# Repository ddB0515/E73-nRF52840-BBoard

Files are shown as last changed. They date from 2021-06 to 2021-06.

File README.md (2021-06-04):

nRF52840-BBoard

Based on Ebyte E73 module with nRF52840
More details here: https://www.ebyte.com/en/product-view-news.aspx?id=445

Managed to fit all into breakout board (4 layers) with Lipo charger (not yet tested fully) and USB-C with modified Adafruit nRF52 Bootloader
https://github.com/ddB0515/Adafruit_nRF52_Bootloader/tree/nrf52840-bboard

when managed to build and get bootloader you need to flash it (I have JLink so was easy to get it flashed)
Double click on reset button to get into DFU mode

Bootloader is in `bootloader` folder and should work if you don't wanna build it

To flash it with JLink all you need is in `bootloader` folder:
nrf52840_bboard_bootloader-0.5.1-2-g881dac1-dirty_s140_6.1.1.hex

To update it via serial(if already flashed via Jlink)

`
adafruit-nrfutil --verbose dfu serial --package nrf52840_bboard_bootloader-0.5.1-2-g881dac1-dirty_s140_6.1.1.zip --port /dev/ttyACM0 -b 115200 --singlebank --touch 1200
`

# Interactive BOM
[Interactive BOM](http://htmlpreview.github.io/?https://raw.githubusercontent.com/ddB0515/nRF52840-BBoard/main/bom/ibom.html)

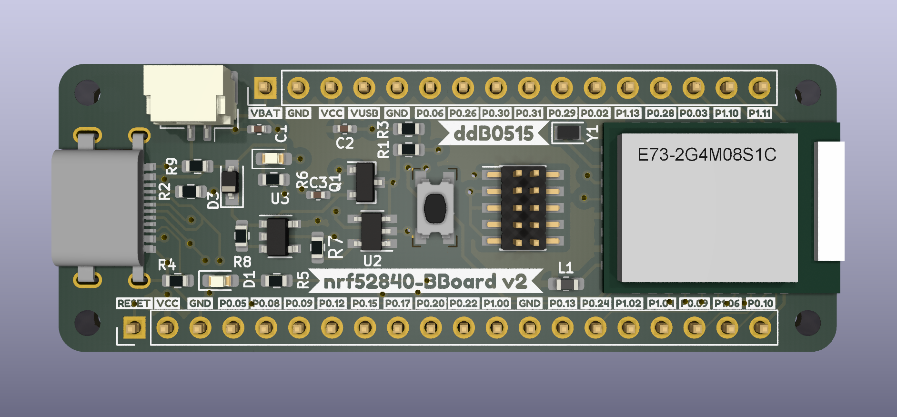
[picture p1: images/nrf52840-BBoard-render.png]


# TODO
- Submit board to Adafruit Bootloader repo
- Add board to Communitiy nRF52 (https://github.com/jpconstantineau/Community_nRF52_Arduino)
- Get more samples/demos to provide with board

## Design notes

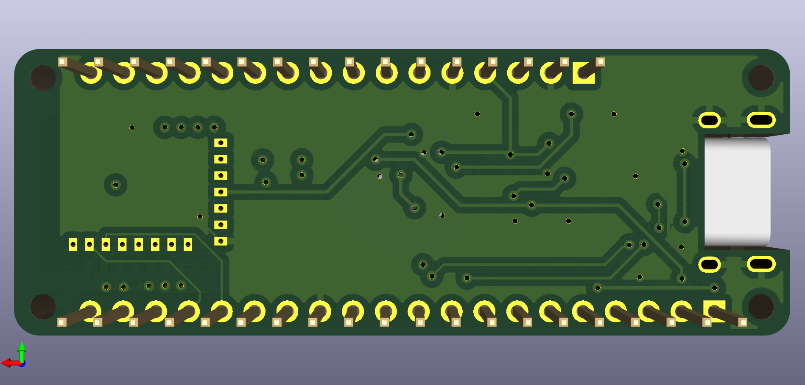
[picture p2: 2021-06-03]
images/nrf52840-BBoard-back.png

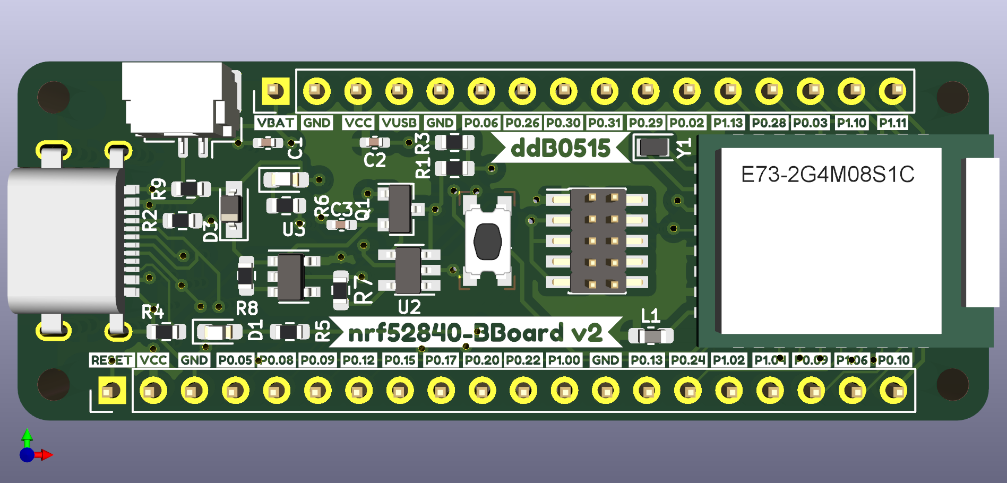
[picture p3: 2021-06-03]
images/nrf52840-BBoard-front.png

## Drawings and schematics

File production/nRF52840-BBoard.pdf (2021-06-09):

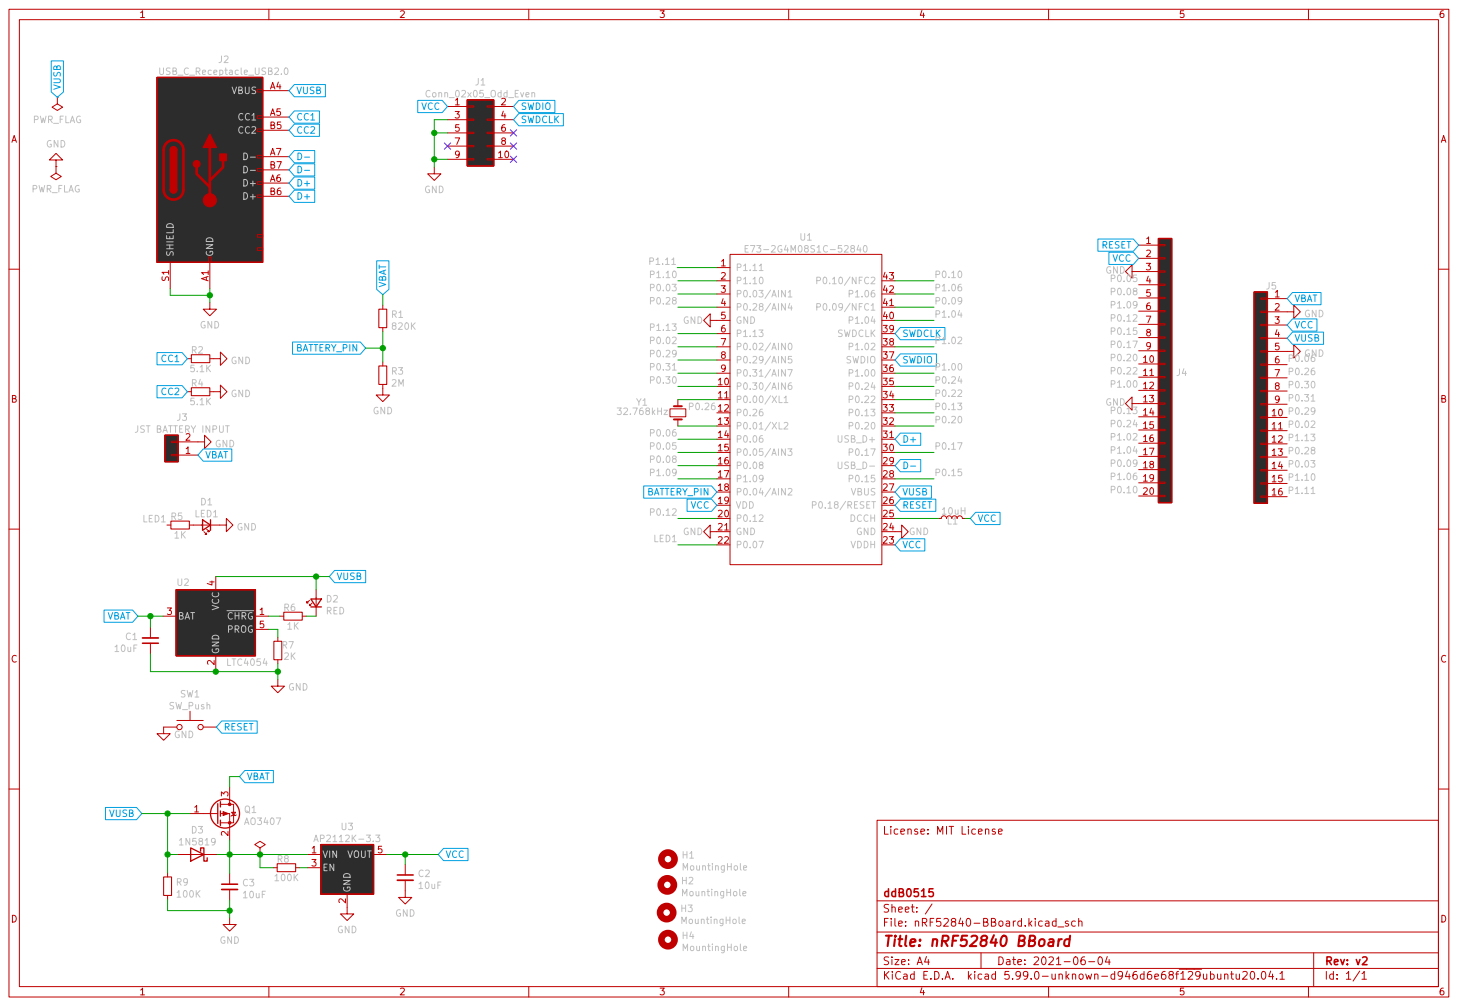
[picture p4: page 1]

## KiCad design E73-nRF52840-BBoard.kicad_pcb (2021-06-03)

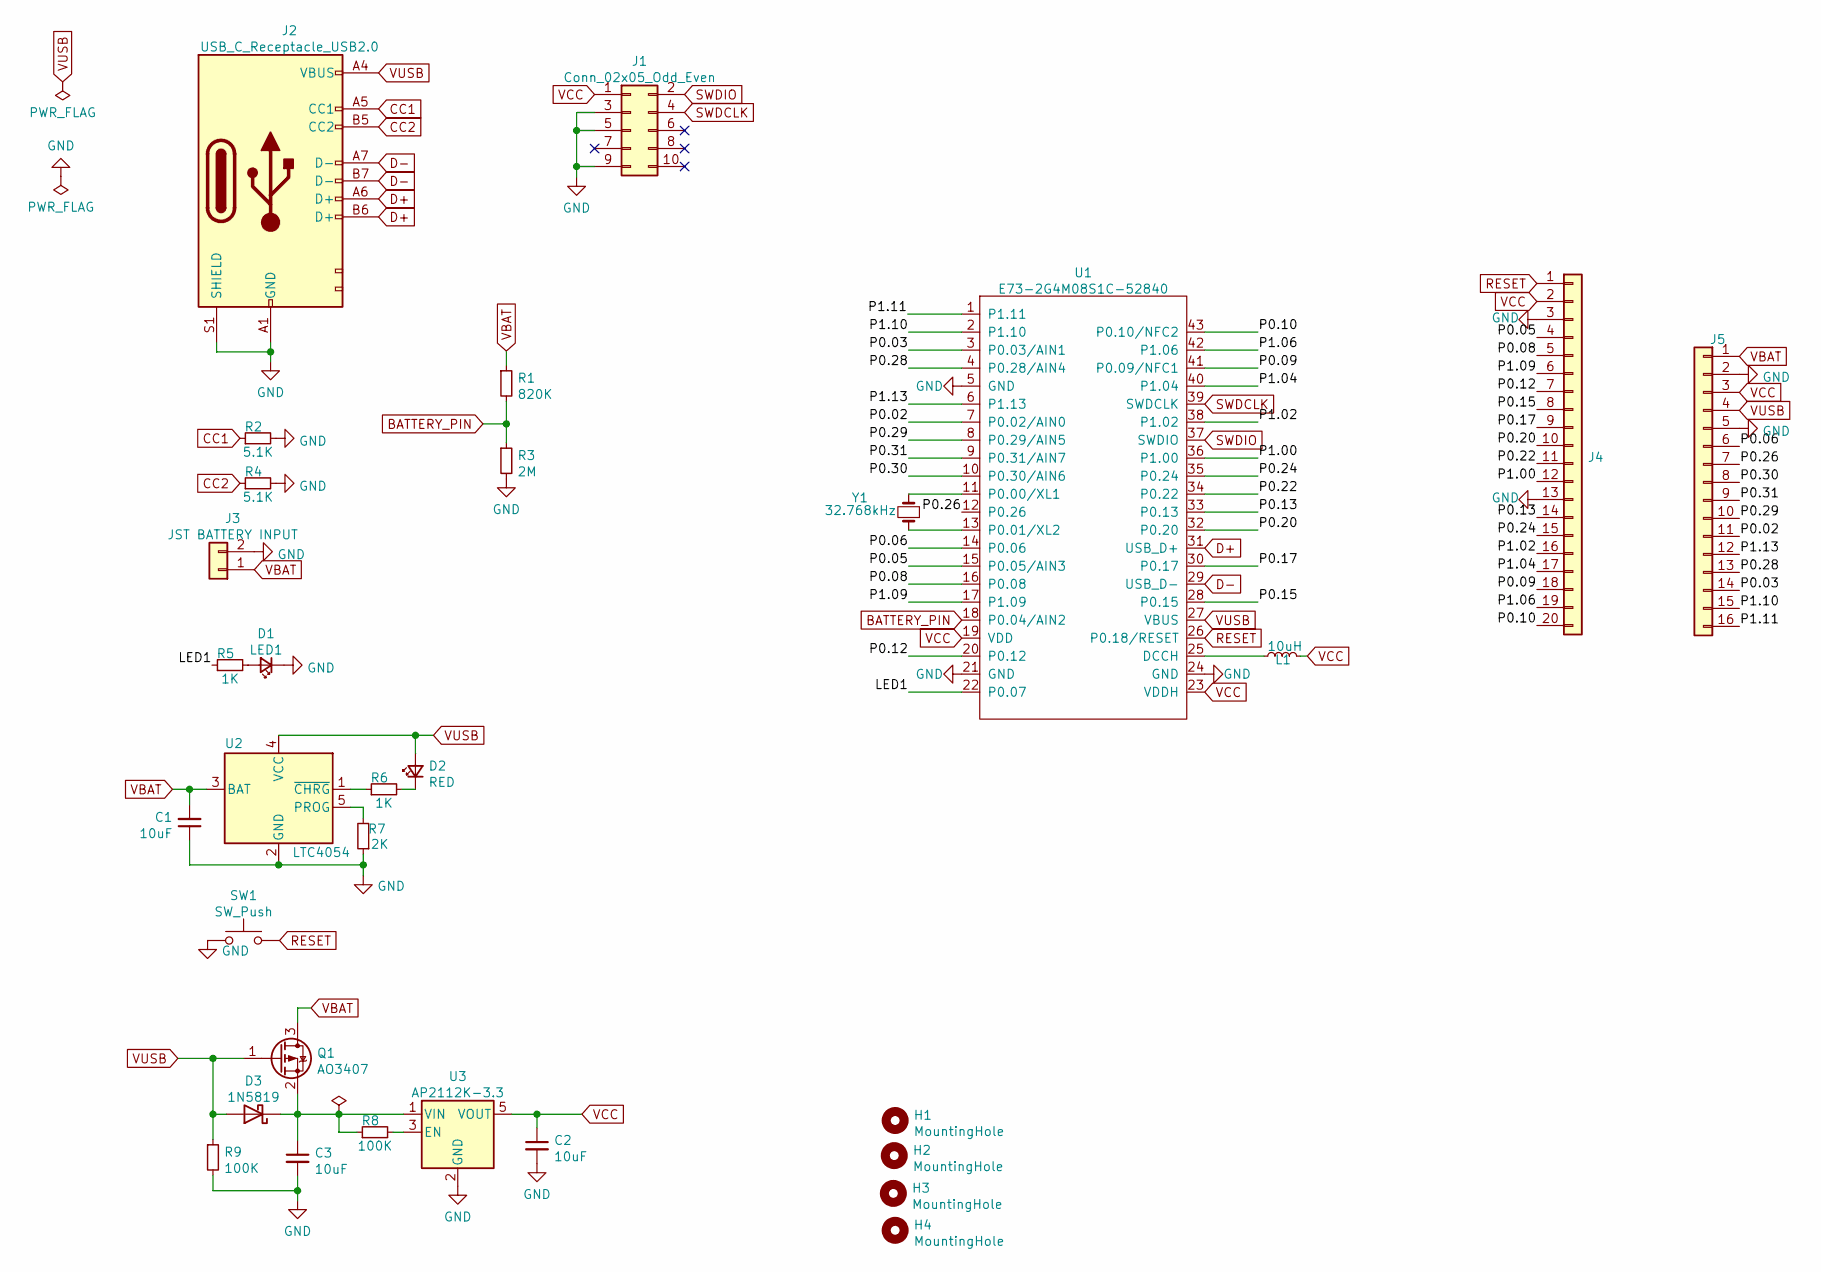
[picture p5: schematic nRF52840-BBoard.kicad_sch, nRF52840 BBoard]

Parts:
C1, C2, C3: 10uF; C_0402_1005Metric_Pad0.74x0.62mm_HandSolder
D1: LED1; LED_0603_1608Metric_Pad1.05x0.95mm_HandSolder
D2: RED; LED_0603_1608Metric_Pad1.05x0.95mm_HandSolder
D3: 1N5819; D_SOD-323_HandSoldering
H1, H2, H3, H4: MountingHole; MountingHole_2mm
J1: Conn_02x05_Odd_Even; PinHeader_2x05_P1.27mm_Vertical_SMD
J2: USB_C_Receptacle_USB2.0; USB-C_C168688
J3: JST BATTERY INPUT; JST_GH_SM02B-GHS-TB_1x02-1MP_P1.25mm_Horizontal
J4: Conn_01x20; PinHeader_1x20_P2.54mm_Vertical
J5: Conn_01x16; PinHeader_1x16_P2.54mm_Vertical
L1: 10uH; L_0603_1608Metric_Pad1.05x0.95mm_HandSolder
Q1: AO3407; SOT-23
R1: 820K; R_0603_1608Metric
R2, R4: 5.1K; R_0603_1608Metric
R3: 2M; R_0603_1608Metric
R5, R6: 1K; R_0603_1608Metric
R7: 2K; R_0603_1608Metric
R8, R9: 100K; R_0603_1608Metric
SW1: SW_Push; KMR621NG
U1: E73-2G4M08S1C-52840
U2: LTC4054; TSOT-23-5
U3: AP2112K-3.3; SOT-23-5
Y1: 32.768kHz; Crystal_SMD_2012-2Pin_2.0x1.2mm

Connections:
/LED1: R5.1, U1.22 (P0.07)
/P0.02: J5.11, U1.7 (P0.02/AIN0)
/P0.03: J5.14, U1.3 (P0.03/AIN1)
/P0.05: J4.4, U1.15 (P0.05/AIN3)
/P0.06: J5.6, U1.14 (P0.06)
/P0.08: J4.5, U1.16 (P0.08)
/P0.09: J4.18, U1.41 (P0.09/NFC1)
/P0.10: J4.20, U1.43 (P0.10/NFC2)
/P0.12: J4.7, U1.20 (P0.12)
/P0.13: J4.14, U1.33 (P0.13)
/P0.15: J4.8, U1.28 (P0.15)
/P0.17: J4.9, U1.30 (P0.17)
/P0.20: J4.10, U1.32 (P0.20)
/P0.22: J4.11, U1.34 (P0.22)
/P0.24: J4.15, U1.35 (P0.24)
/P0.26: J5.7, U1.12 (P0.26)
/P0.28: J5.13, U1.4 (P0.28/AIN4)
/P0.29: J5.10, U1.8 (P0.29/AIN5)
/P0.30: J5.8, U1.10 (P0.30/AIN6)
/P0.31: J5.9, U1.9 (P0.31/AIN7)
/P1.00: J4.12, U1.36 (P1.00)
/P1.02: J4.16, U1.38 (P1.02)
/P1.04: J4.17, U1.40 (P1.04)
/P1.06: J4.19, U1.42 (P1.06)
/P1.09: J4.6, U1.17 (P1.09)
/P1.10: J5.15, U1.2 (P1.10)
/P1.11: J5.16, U1.1 (P1.11)
/P1.13: J5.12, U1.6 (P1.13)
BATTERY_PIN: R1.2, R3.1, U1.18 (P0.04/AIN2)
CC1: J2.A5 (CC1), R2.1
CC2: J2.B5 (CC2), R4.1
D+: J2.A6 (D+), J2.B6 (D+), U1.31 (USB_D+)
D-: J2.A7 (D-), J2.B7 (D-), U1.29 (USB_D-)
GND: C1.1, C2.2, C3.2, D1.1 (K), J1.3, J1.5, J1.9, J2.A1 (GND), J2.S1 (SHIELD), J3.2, J4.3, J4.13, J5.2, J5.5, R2.2, R3.2, R4.2, R7.1, R9.2, SW1.1, U1.5 (GND), U1.21 (GND), U1.24 (GND), U2.2 (GND), U3.2 (GND)
unnamed: C3.1, D3.1 (K), Q1.2 (S), R8.1, U3.1 (VIN)
unnamed: D1.2 (A), R5.2
unnamed: D2.1 (K), R6.2
unnamed: L1.1, U1.25 (DCCH)
unnamed: R6.1, U2.1 (~CHRG)
unnamed: R7.2, U2.5 (PROG)
unnamed: R8.2, U3.3 (EN)
unnamed: U1.11 (P0.00/XL1), Y1.2
unnamed: U1.13 (P0.01/XL2), Y1.1
RESET: J4.1, SW1.2, U1.26 (P0.18/RESET)
SWDCLK: J1.4, U1.39 (SWDCLK)
SWDIO: J1.2, U1.37 (SWDIO)
VBAT: C1.2, J3.1, J5.1, Q1.3 (D), R1.1, U2.3 (BAT)
VCC: C2.1, J1.1, J4.2, J5.3, L1.2, U1.19 (VDD), U1.23 (VDDH), U3.5 (VOUT)
VUSB: D2.2 (A), D3.2 (A), J2.A4 (VBUS), J5.4, Q1.1 (G), R9.1, U1.27 (VBUS), U2.4 (VCC)

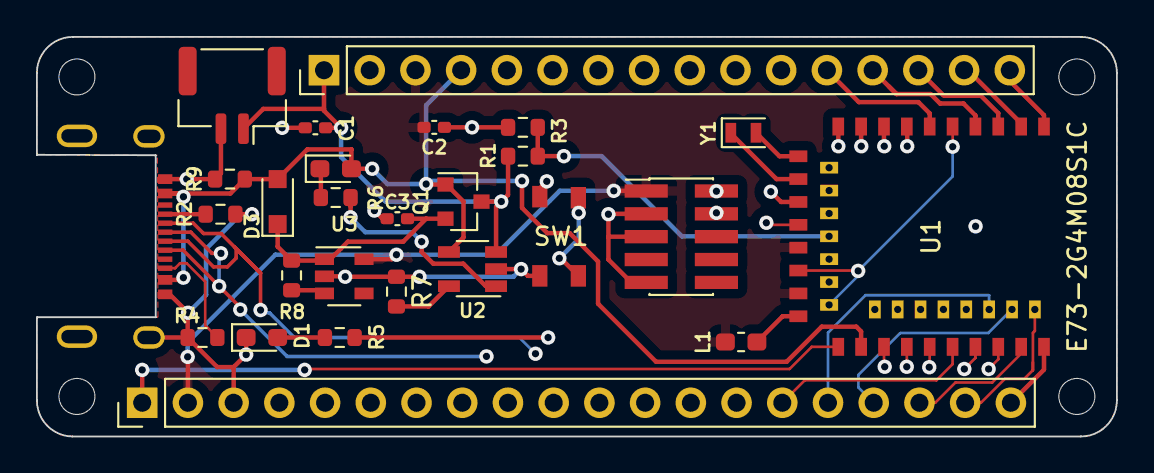
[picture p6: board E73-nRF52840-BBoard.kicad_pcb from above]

Board: 4 copper layers, 60.0 x 22.2 mm, 31 parts (0 on the bottom side), 49 nets.

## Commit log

2021-06-03 initial rev1
    [E73-nRF52840-BBoard-B_Cu.gbr, E73-nRF52840-BBoard-B_Mask.gbr, E73-nRF52840-BBoard-B_Paste.gbr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]
2021-06-03 added final version after testing
    [E73-nRF52840-BBoard.dsn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]
2021-06-04 added pdf schematic
2021-06-04 small changes to schematic
    [nRF52840-BBoard.kicad_sch]
2021-06-04 added openmoko PID?VID in bootloader
2021-06-09 updated files
    [nRF52840-BBoard-B_Cu.gbr, nRF52840-BBoard-B_Mask.gbr, nRF52840-BBoard-B_Paste.gbr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]

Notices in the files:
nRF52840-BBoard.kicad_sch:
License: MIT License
